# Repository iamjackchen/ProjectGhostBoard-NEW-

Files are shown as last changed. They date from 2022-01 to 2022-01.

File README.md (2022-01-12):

# ProjectGhostBoard

Hello thereeee

This is a site for me to document my current ongoing project a low profile wireless mechanical keyboard. Originally started this a few years ago back when I was in middle school (my macbook air had a semi-broken keyboard and I was just getting into the world of mechanical keyboards, AND there was a new set of low profile mechanical switches on the market) 

But who even knows anything about electronics engineering at that age? Took me a few years and attempts to slowly figure stuff out (you can see where I got to in my last attempt here, made when I was in G10: https://github.com/iamjackchen/ProjectGhostboard-OLD-)

<br/>

### About the Project

Enough with the history, moving onto the project itself. The original design goal was to build a low profile (i.e. portable) mechanical keyboard. The portable aspect also prompted me to pursue Bluetooth functionality ~~which might have possibly been the worst decision I have ever made in terms of trying to actually finish this project~~.
Here were my original design blueprints: 

<br/>

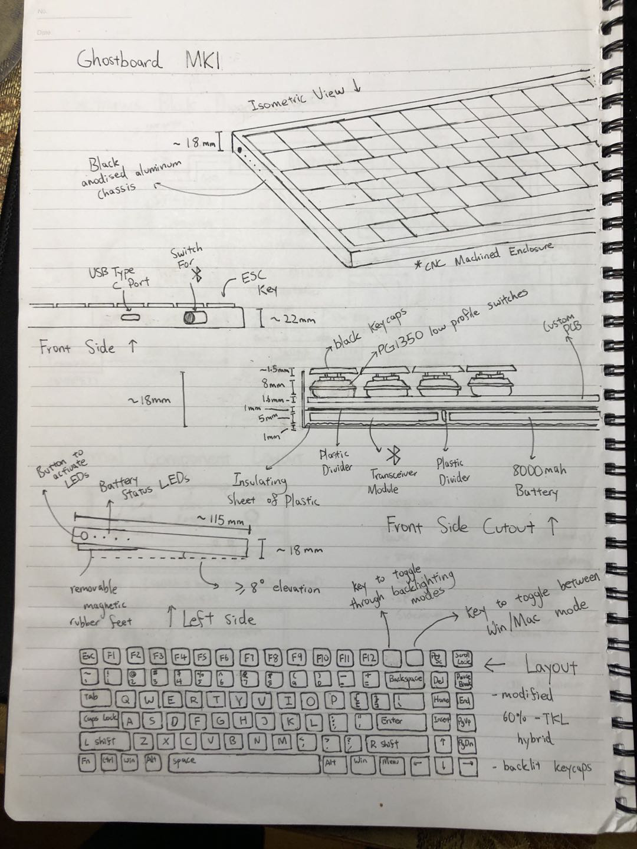
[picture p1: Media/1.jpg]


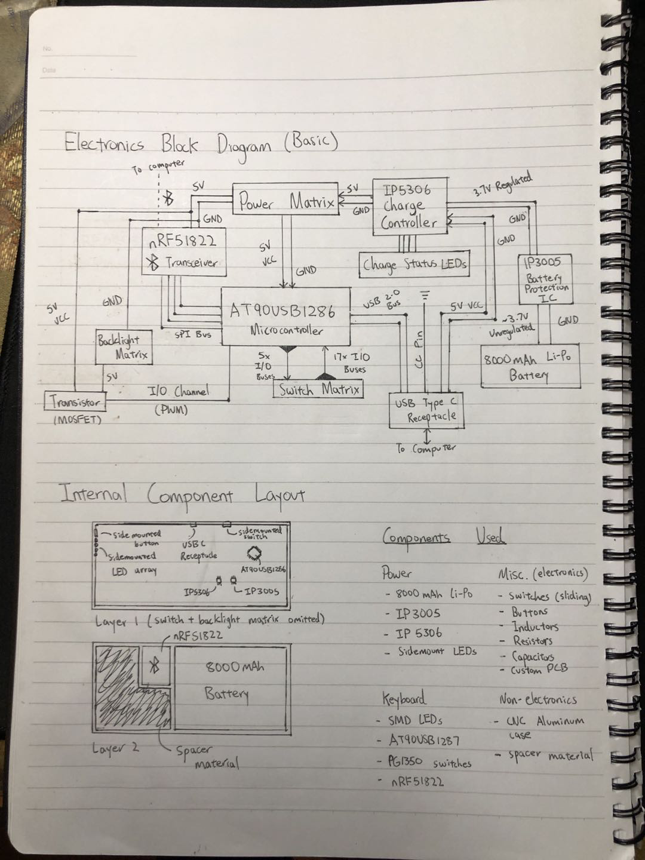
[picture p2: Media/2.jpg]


<br/>

The design has evolved a little (along with my knowledge of embedded systems and keyboard assembly 😂) but the general principle remains the same. A 75%-ish layout with PCB-mounted low profile switches (PG1350 - I'm using the brown/tactile variant) and white multi-level backlight. No disgusting rgb. Originally when the PG1350 line was released I tried to make this the first true low-profile wireless keyboard on the market but obviously that didn't happen lmao. The layout I eventually settled for is below:

<br/>

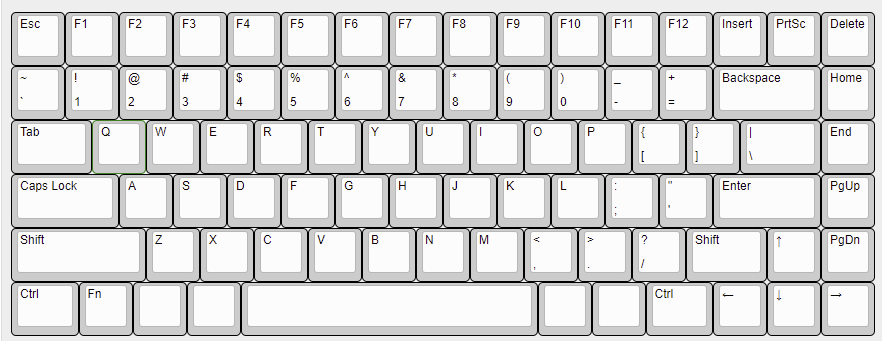
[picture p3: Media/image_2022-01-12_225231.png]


<br/>

The current PCB design (in the electronics folder) uses a USB-power gated MOSFET to regulate power delivery from the battery to the main circuit, an MCU-gated MOSFET to control charging (power flow to the battery) and a MCU-gated MOSFET to trigger Bluetooth. The intention of the MCU-gated control charging MOSFET is for the user to be able to disable charging when the keyboard is being plugged in over long periods of time for battery longevity. I'll probably use raw-hid to have some sort of computer-keyboard communication and write a desktop client that can tell the keyboard to disable charging. Maybe in the futre I can use raw-hid and a desktop client for other purposes (macros, backlight settings, and etc)

Some other design considerations and features with regards to electronics:
  - USB Type C
  - Battery charge indicator
  - HID over BLE

The software that makes all of this come together is [QMK](https://github.com/qmk/qmk_firmware). It's a keyboard firmware written in C and I am immensely grateful to its creators. And yes, for all new programmers here, do learn C or C++ before Python and *not* the other way around. You will thank me.

I havent gotten far enough to worry too much about the physical enclosure and keyboard assembly but I will have (hopefully) some CAD files, screenshots, and renders hanging out in this repo soon!! As of now I am aware that the PG1350 requires a thinner (1.2mm) plate and the stabilisers are mounted to the PCB (with plate cutouts needed). 

<br/>
If you've read this far, thank you so much for taking interest, and I hope to bear good news of progress soon. Below is a gallery of certain snippets from this awesome journey. 

----

# Gallery

### Current PCB Progress Renders (Coming soon)
Stay tuned.

<br/>

### Power Delivery Circuit Tester
Small PCB to test out my USB-C power delivery designs. Used an IC originally meant for power bank charging (IP5306 if anyone's interested) along with an FS8205A and a DW01 for battery surge protection. I had a lot of trouble soldering on header pins so I stripped two wires for it. Janky? Yes. But it works 😂

<br/>

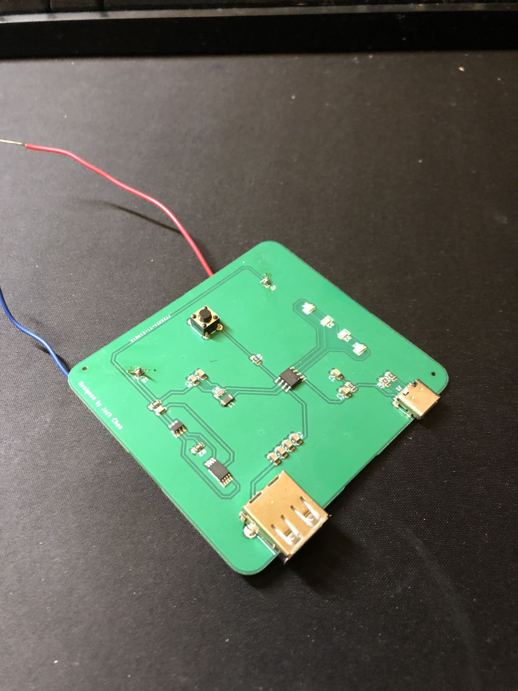
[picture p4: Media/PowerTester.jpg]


<br/>

Here's it in action with a 4000mAh lipo I had lying around from the last attempt at making this keyboard:

<br/>

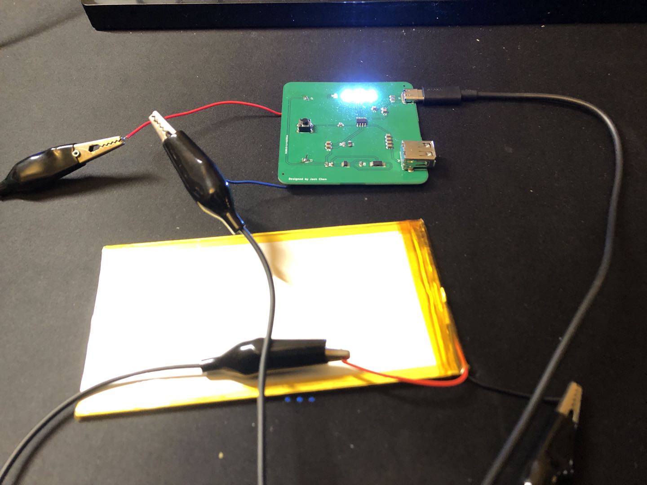
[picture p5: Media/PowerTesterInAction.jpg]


<br/>

### Proof of Concept
This is a demo of a proof of concept that my parents made me build before they would sponsor any further work of a custom  PCB. On the breadboard I have a Teensy2.0++ (ATUSB1286, the MCU I use in my custom PCB) wired to an Adafruit BLE module via SPI and a 4x4 tester matrix of generic buttons. I built this a while ago but lost the original video so I filmed it again a few days ago. Starring Antoni's new M1X MBP. 

<br/>

(https://youtu.be/-FnGQFiSdFY)

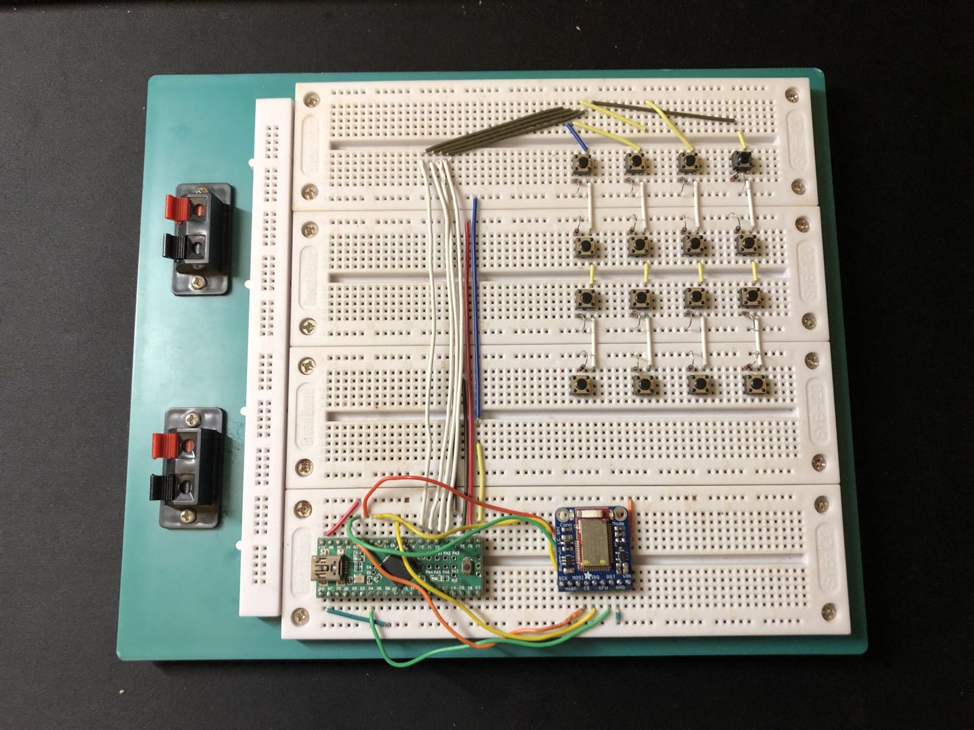
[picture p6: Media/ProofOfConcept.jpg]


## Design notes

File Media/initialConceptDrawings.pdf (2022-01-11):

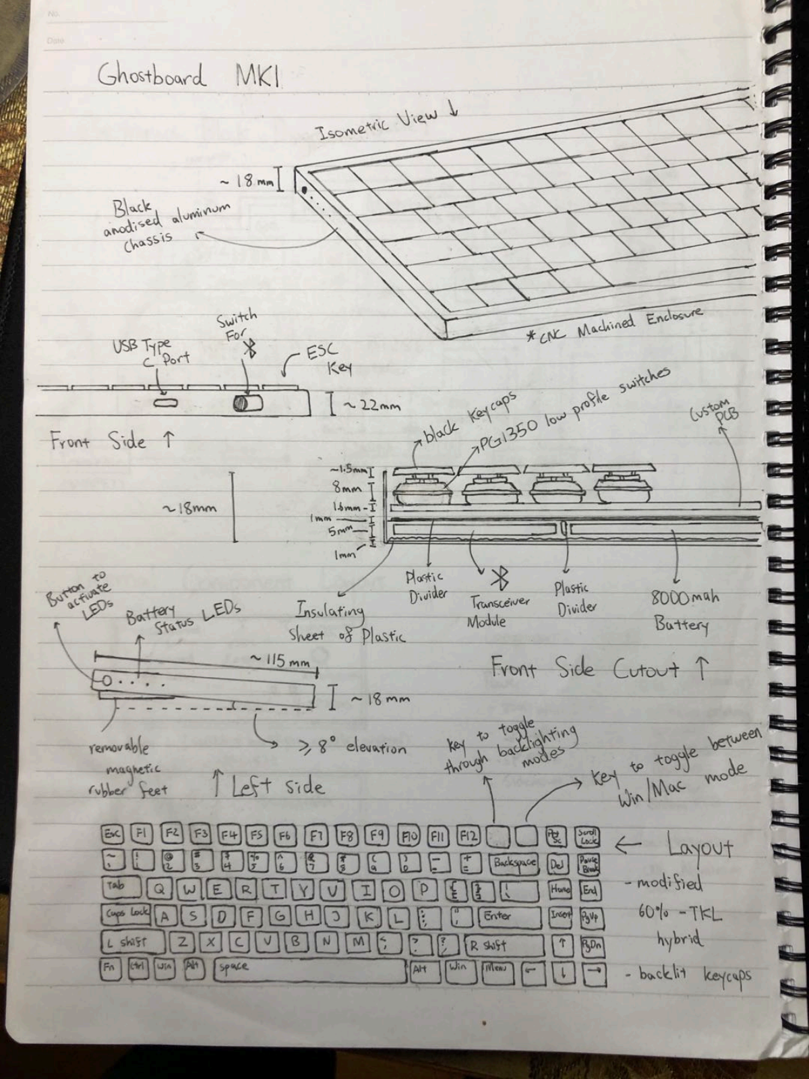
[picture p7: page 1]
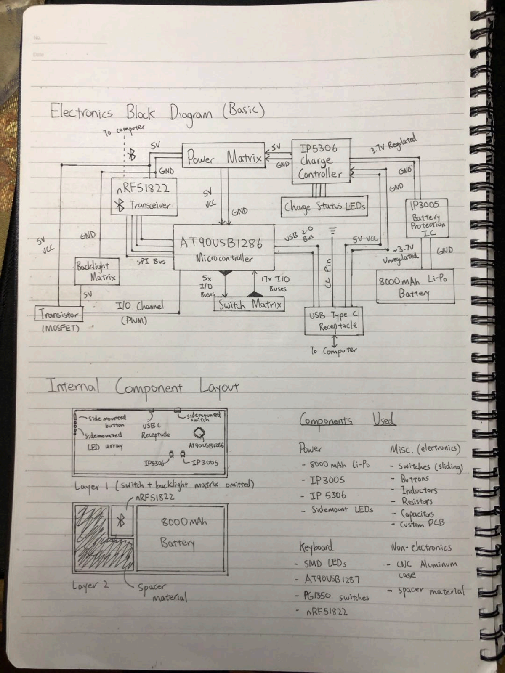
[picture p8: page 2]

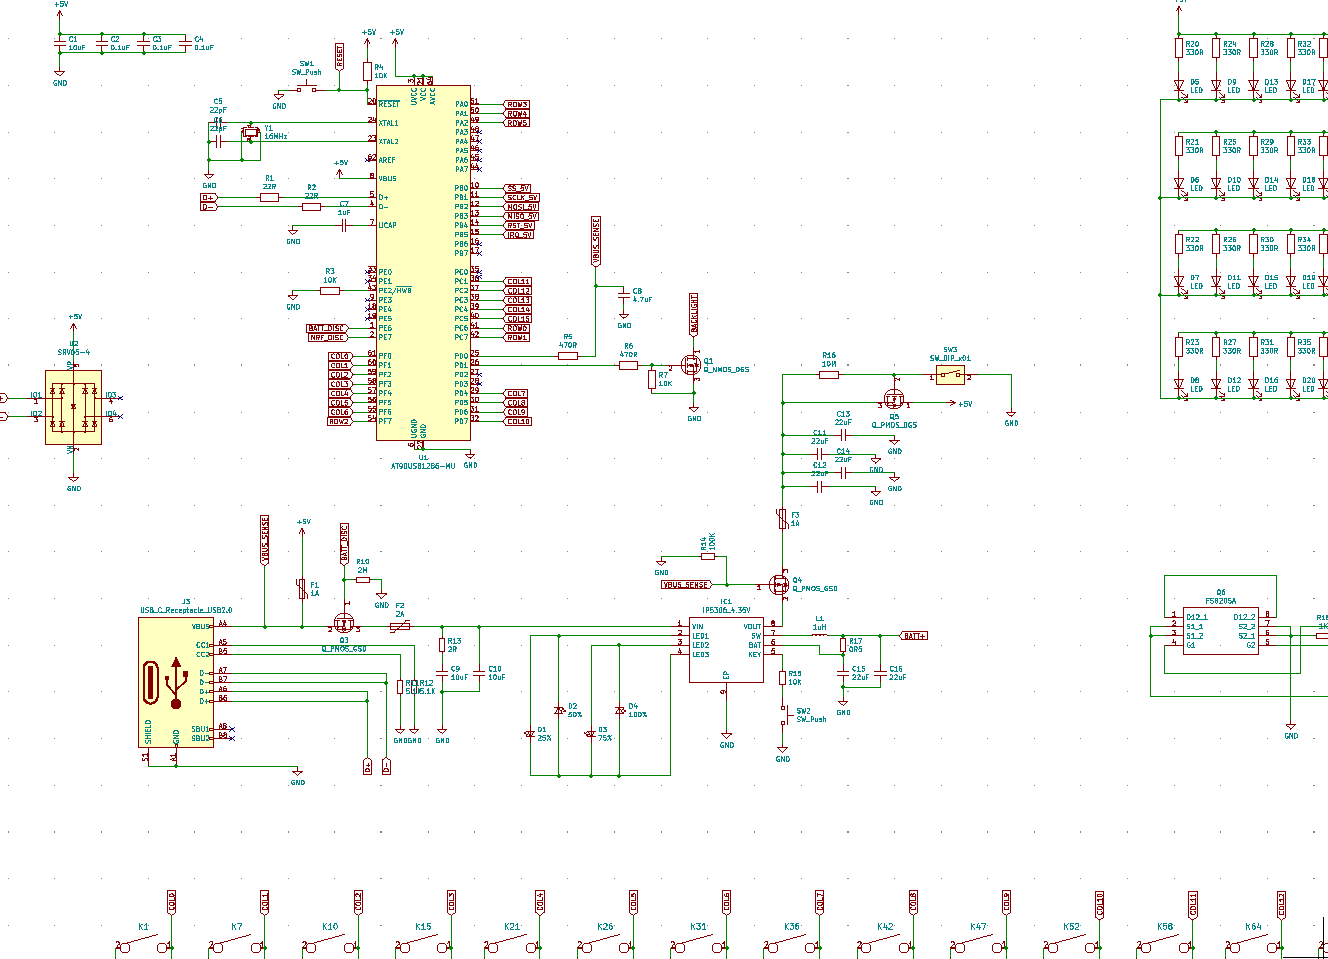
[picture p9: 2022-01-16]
Media/SchematicSS.png

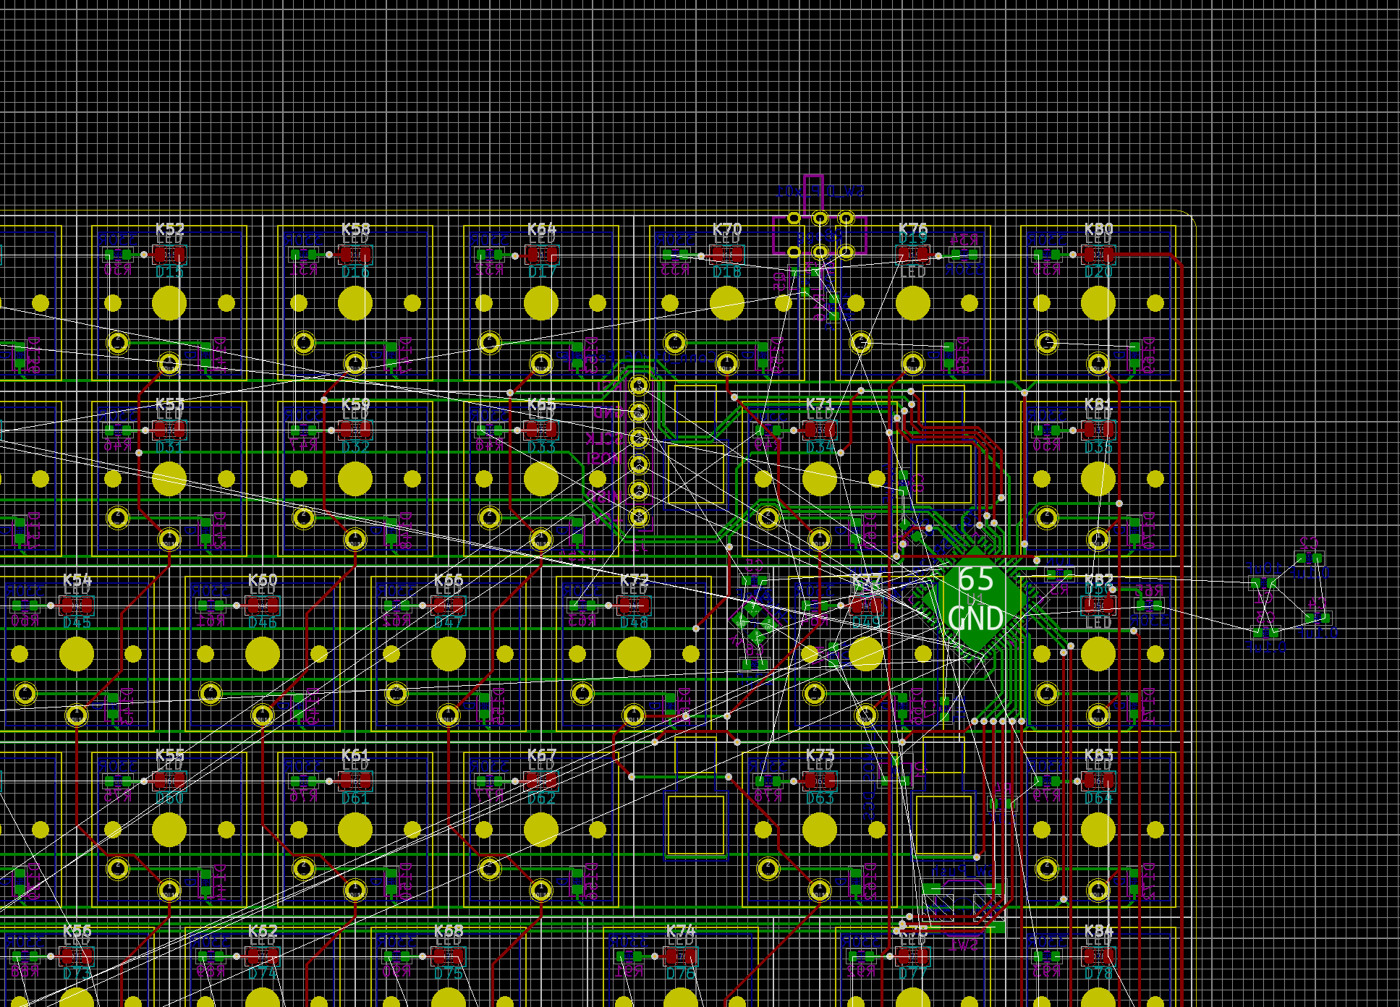
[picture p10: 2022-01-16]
Media/PCBSS.png

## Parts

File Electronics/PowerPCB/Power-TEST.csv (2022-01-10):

Comment | Designator | Footprint | LCSC
10uF | C1,C2 | Capacitor_SMD:C_0805_2012Metric_Pad1.18x1.45mm_HandSolder
0.1uF | C3 | Capacitor_SMD:C_0603_1608Metric_Pad1.08x0.95mm_HandSolder
22uF | C4,C5,C6,C7,C8,C9 | Capacitor_SMD:C_0805_2012Metric_Pad1.18x1.45mm_HandSolder
25% | D1 | LED_SMD:LED_0805_2012Metric_Pad1.15x1.40mm_HandSolder | C2290
50% | D2 | LED_SMD:LED_0805_2012Metric_Pad1.15x1.40mm_HandSolder | C2290
75% | D3 | LED_SMD:LED_0805_2012Metric_Pad1.15x1.40mm_HandSolder | C2290
100% | D4 | LED_SMD:LED_0805_2012Metric_Pad1.15x1.40mm_HandSolder | C2290
DW01 | IC1 | PCBFootprints:DW01 | C14213
IP5306_4.35V | IC2 | PCBFootprints:IP5306 | C384572
USB_C_Receptacle_USB2.0 | J1 | Connector_USB:USB_C_Receptacle_HRO_TYPE-C-31-M-12 | C136423
Cell+ | J2 | Connector_PinSocket_2.54mm:PinSocket_1x01_P2.54mm_Vertical
Cell- | J3 | Connector_PinSocket_2.54mm:PinSocket_1x01_P2.54mm_Vertical
USB_A | J4 | Connector_USB:USB_A_Stewart_SS-52100-001_Horizontal | C2346
1uH | L1 | Inductor_SMD:L_0805_2012Metric_Pad1.05x1.20mm_HandSolder
FS8205A | Q1 | PCBFootprints:FS8205A | C16052
2R | R1 | Resistor_SMD:R_0805_2012Metric_Pad1.20x1.40mm_HandSolder
1K | R2 | Resistor_SMD:R_0805_2012Metric_Pad1.20x1.40mm_HandSolder
100R | R3 | Resistor_SMD:R_0805_2012Metric_Pad1.20x1.40mm_HandSolder
10K | R4 | Resistor_SMD:R_0805_2012Metric_Pad1.20x1.40mm_HandSolder
0R5 | R5 | Resistor_SMD:R_0805_2012Metric_Pad1.20x1.40mm_HandSolder
5.1K | R6,R7 | Resistor_SMD:R_0805_2012Metric_Pad1.20x1.40mm_HandSolder
SW_Push | SW1 | Button_Switch_THT:SW_PUSH_6mm_H4.3mm

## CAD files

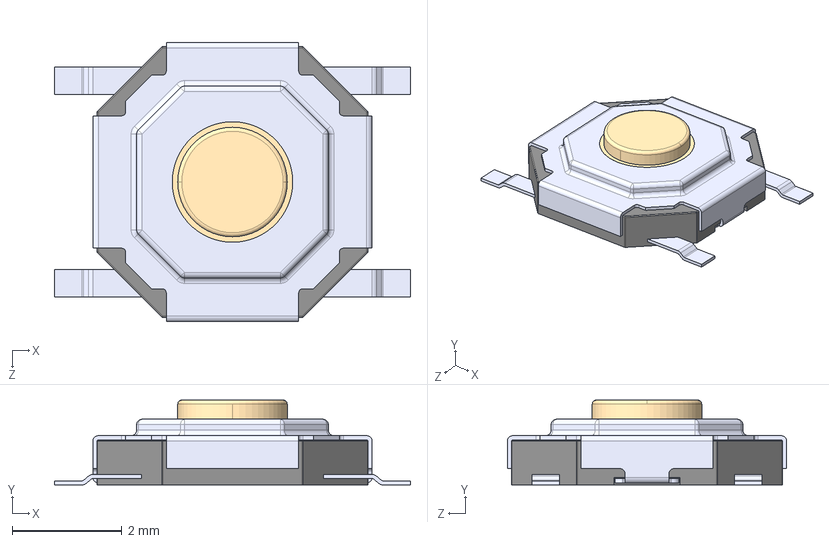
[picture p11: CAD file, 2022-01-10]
Electronics/PCBModels/TS-1187A-B-A-B.step
6.50 x 1.55 x 5.10 mm

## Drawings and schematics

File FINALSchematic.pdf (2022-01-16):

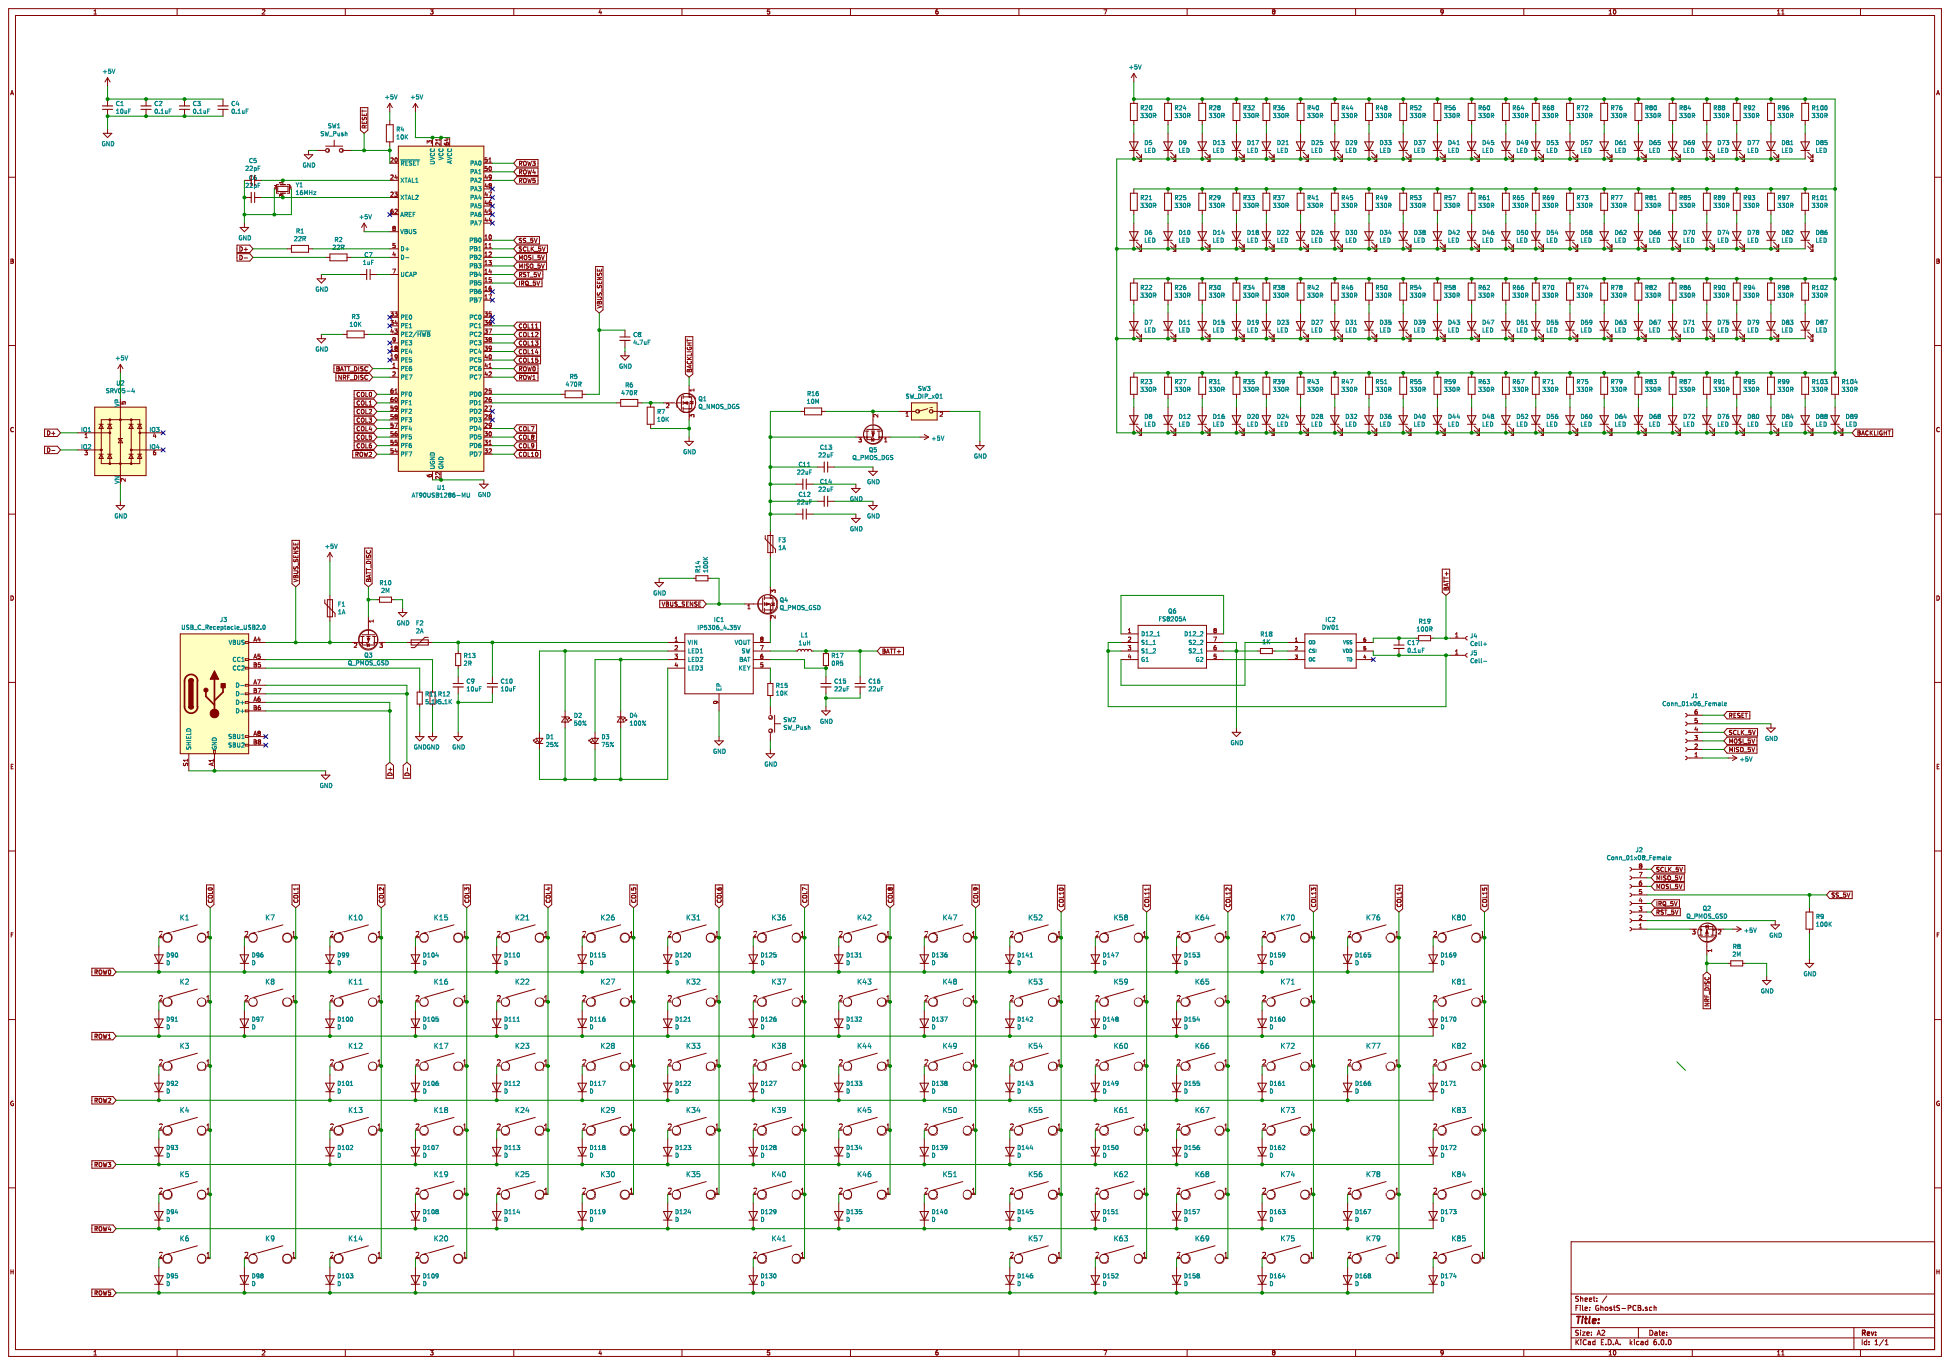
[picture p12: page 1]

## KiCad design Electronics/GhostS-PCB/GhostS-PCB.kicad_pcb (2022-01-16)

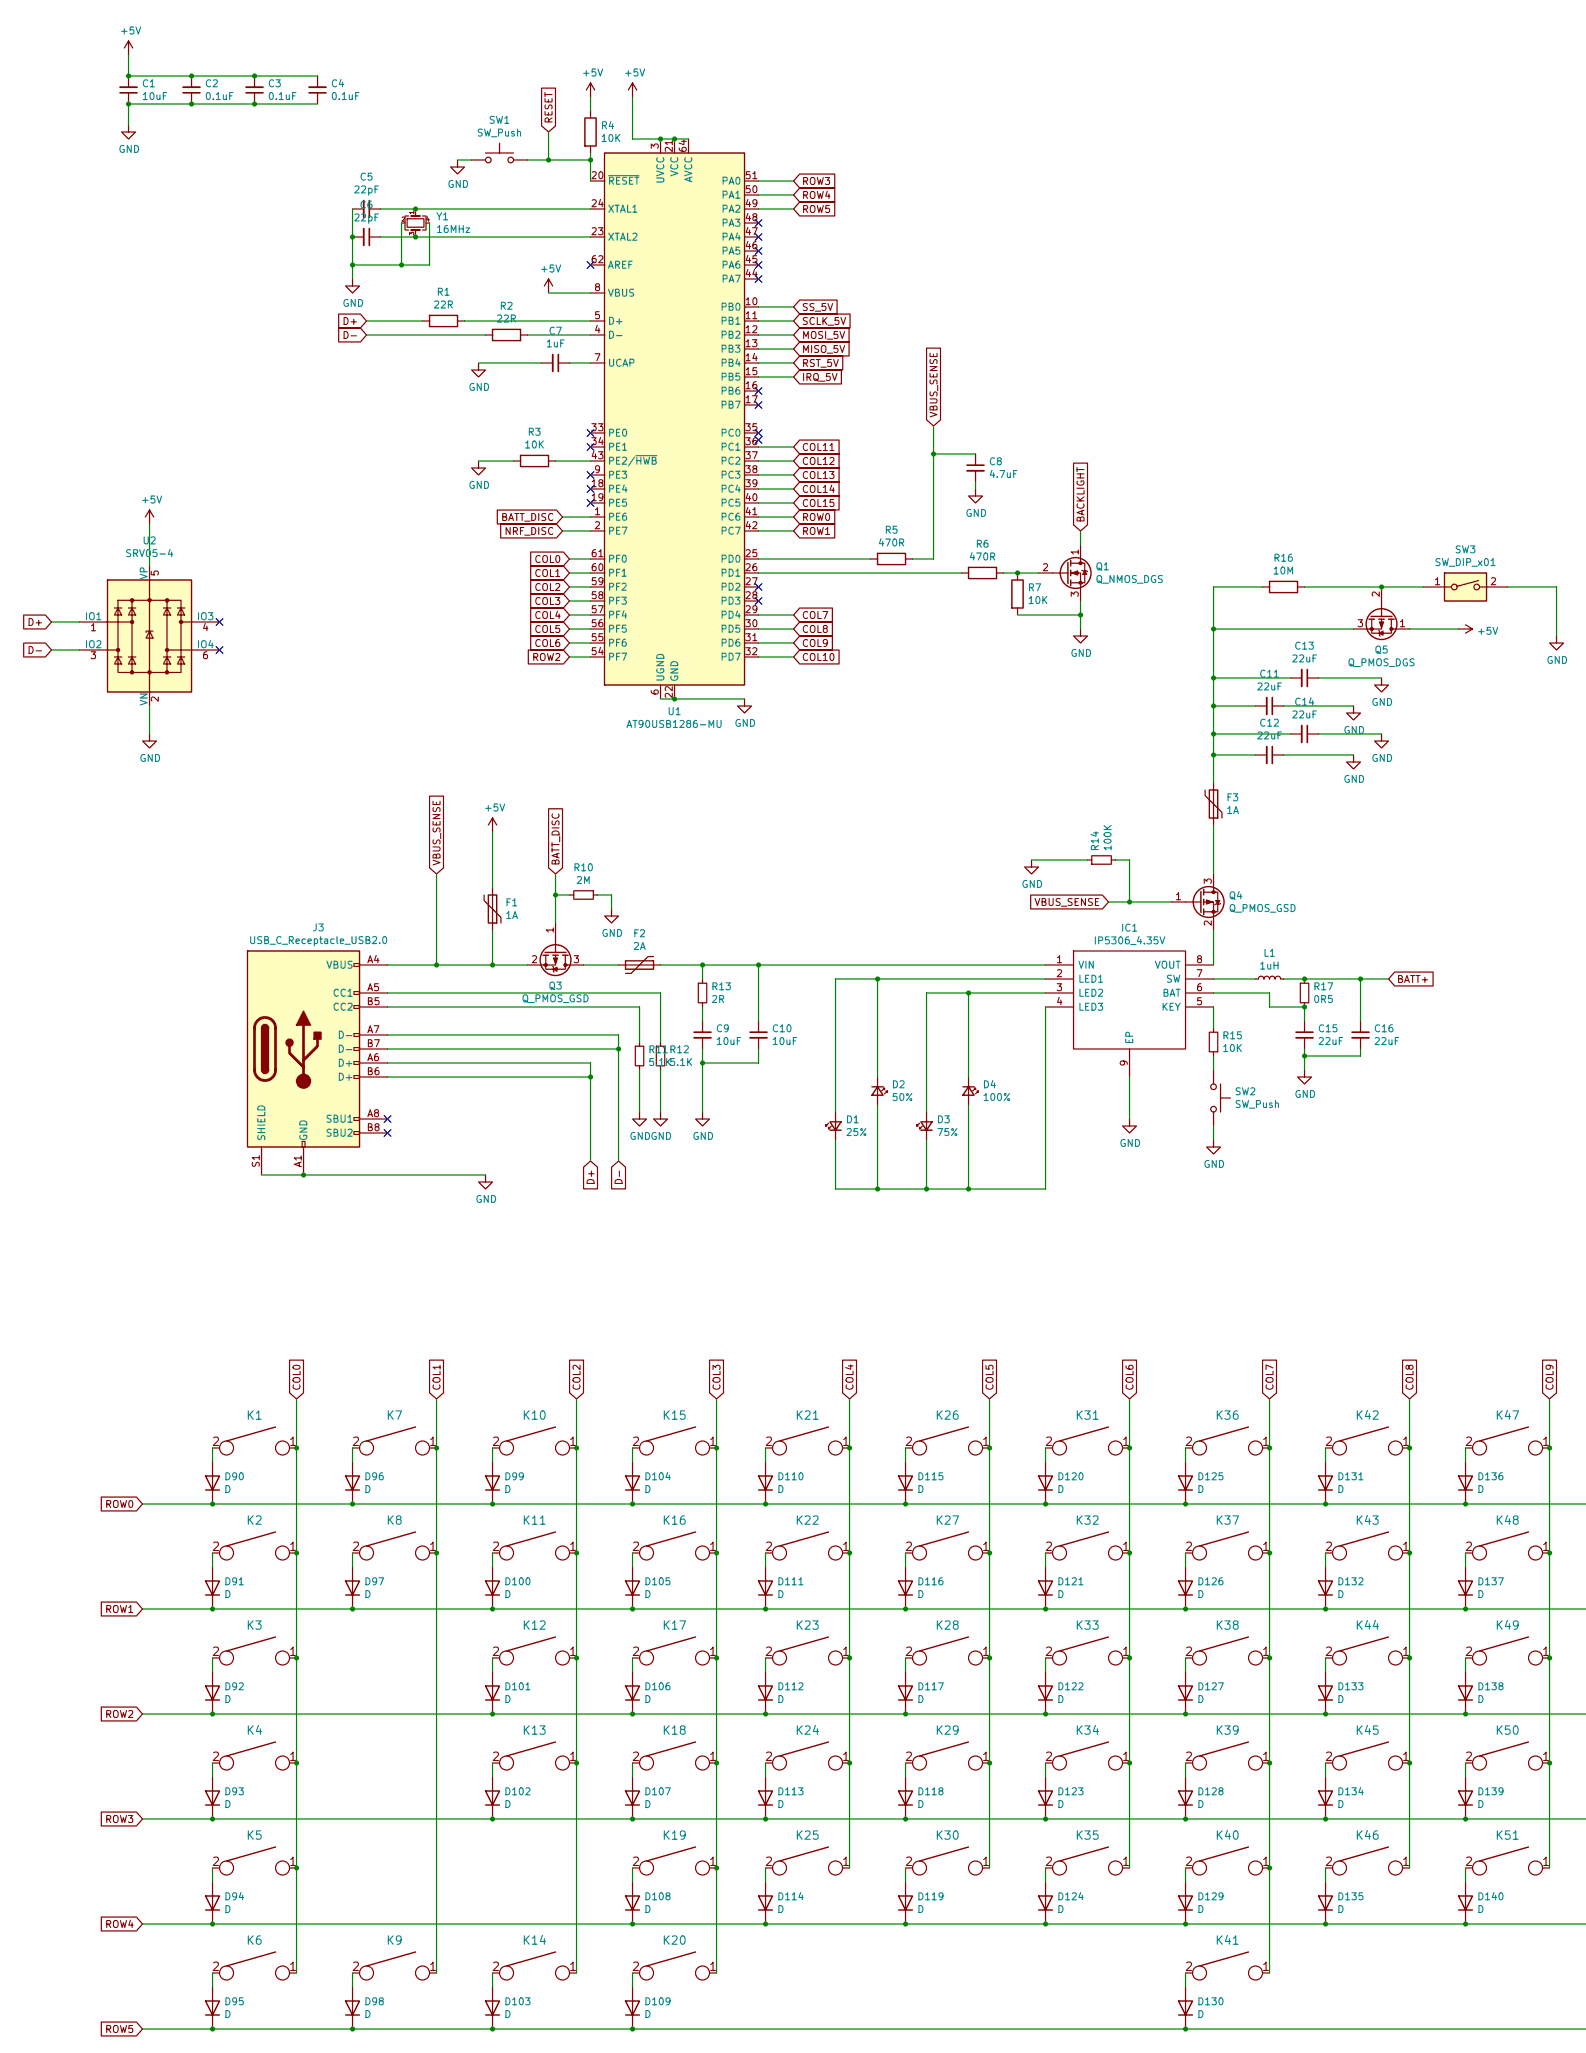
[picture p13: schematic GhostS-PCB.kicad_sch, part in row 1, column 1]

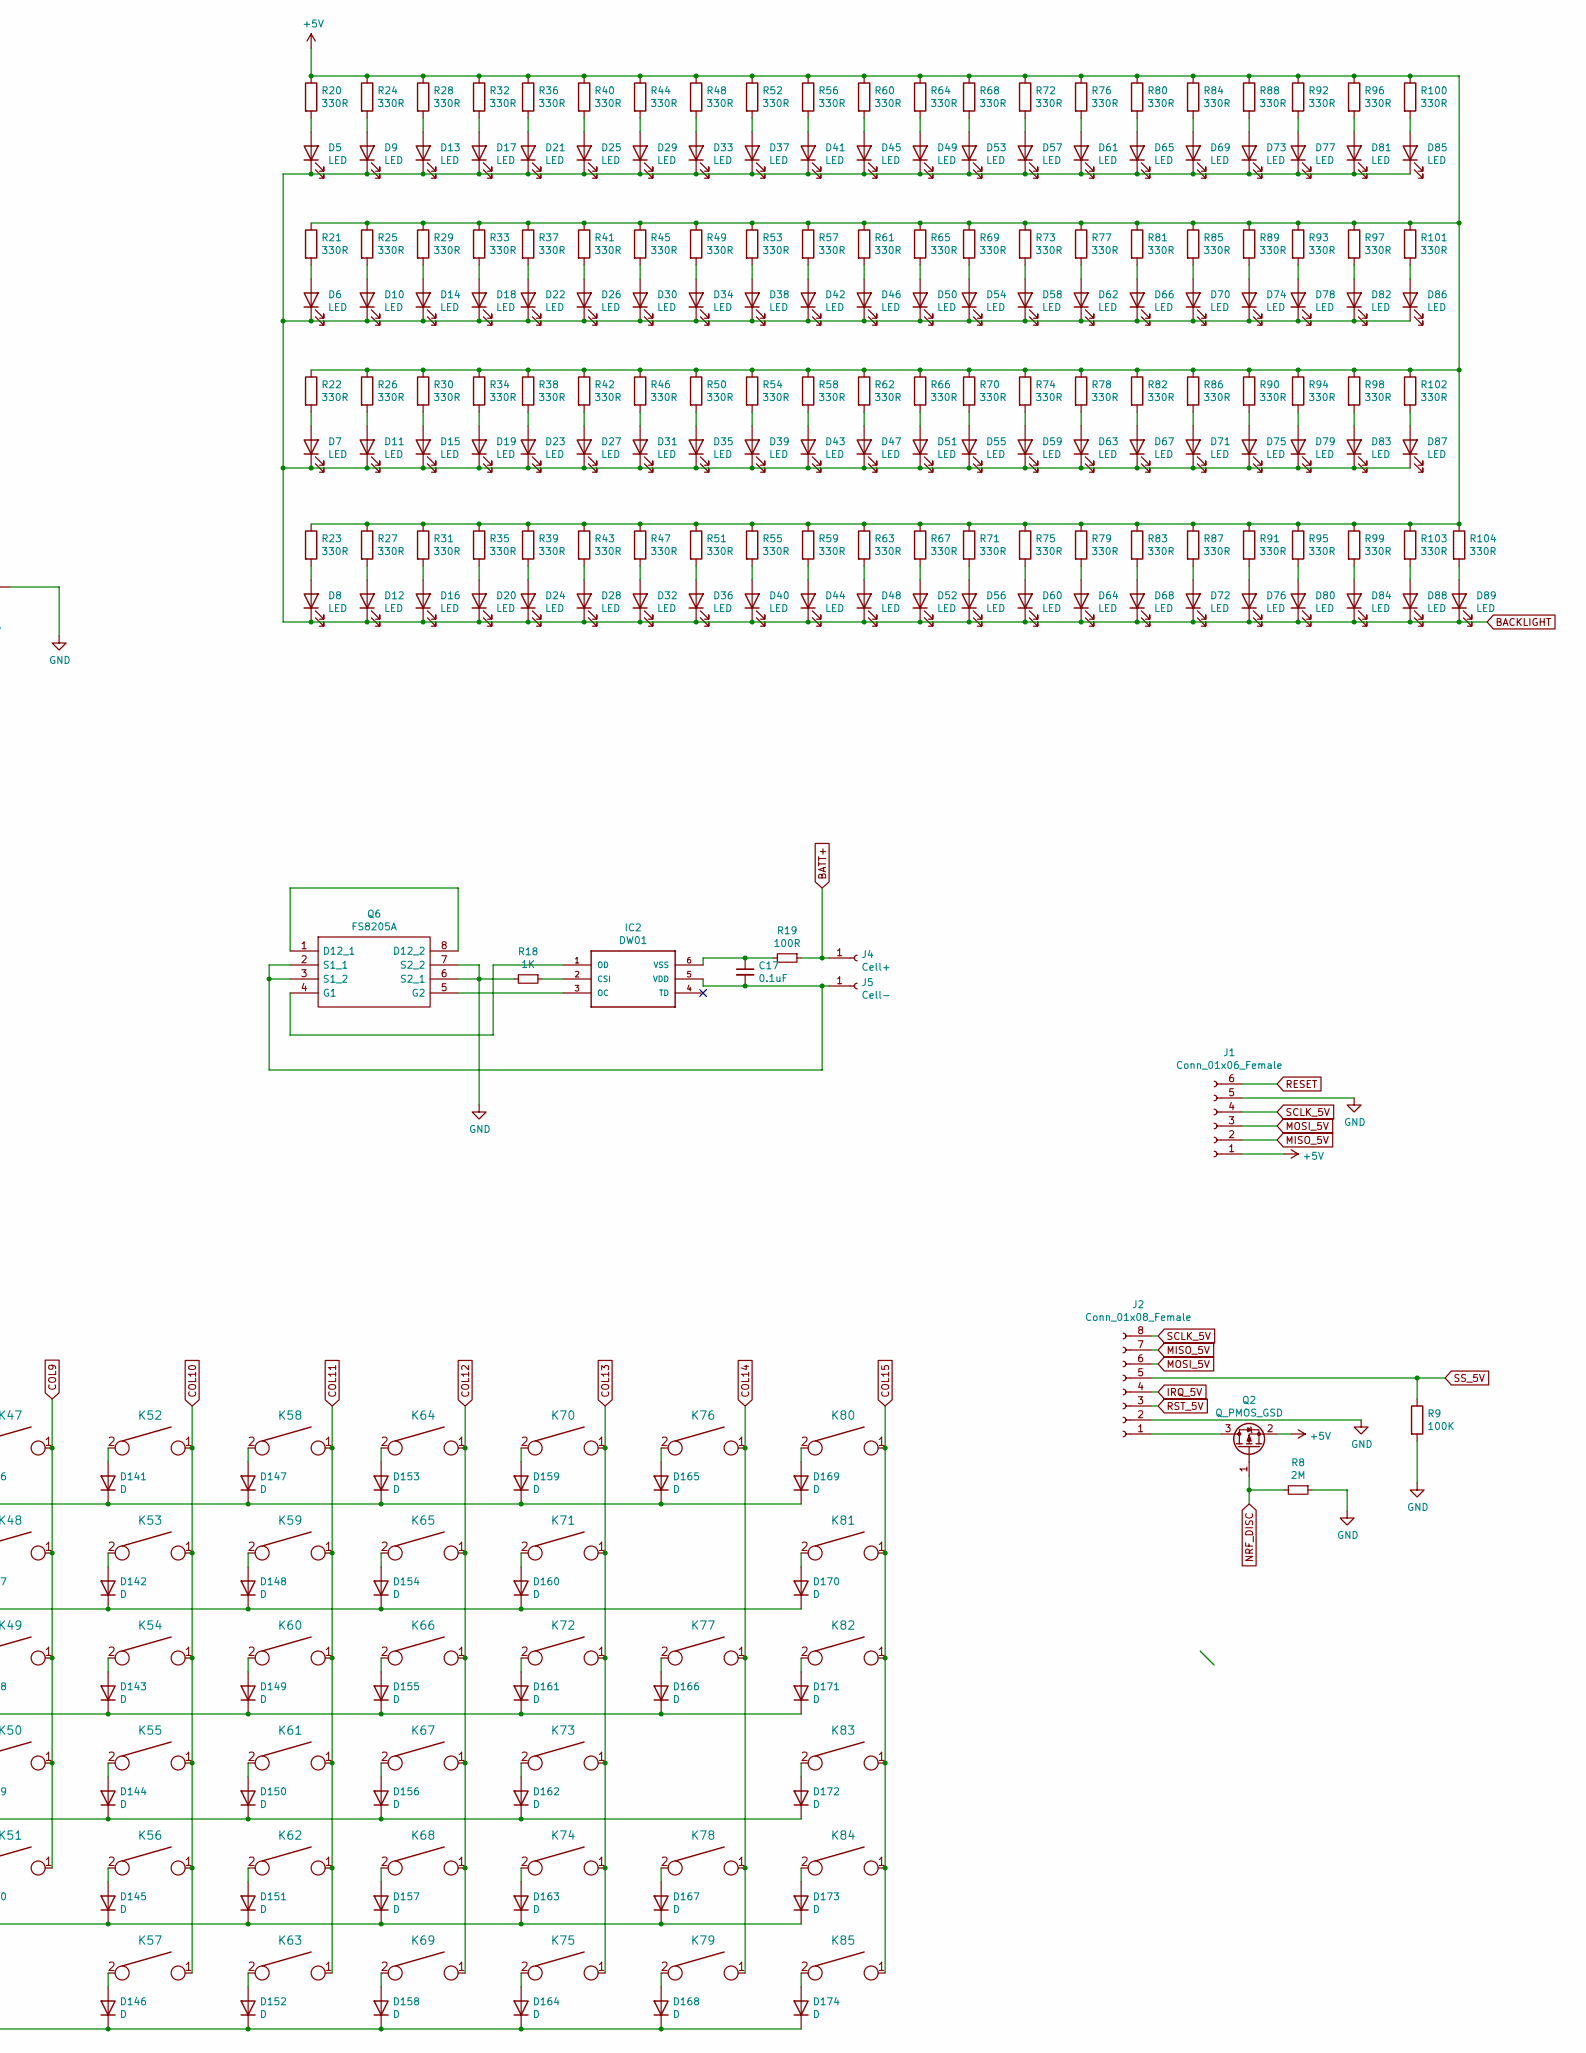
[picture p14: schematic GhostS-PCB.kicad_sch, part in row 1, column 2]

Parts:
C1, C9, C10: 10uF; C_0603_1608Metric
C2, C3, C4, C17: 0.1uF; C_0603_1608Metric
C5, C6: 22pF; C_0603_1608Metric
C7: 1uF; C_0603_1608Metric
C8: 4.7uF; C_0603_1608Metric
C11, C12, C13, C14, C15, C16: 22uF; C_0603_1608Metric
D1: 25%; LED_1206_3216Metric; LCSC C2290
D2: 50%; LED_1206_3216Metric; LCSC C2290
D3: 75%; LED_1206_3216Metric; LCSC C2290
D4: 100%; LED_1206_3216Metric; LCSC C2290
D5, D6, D7, D8, D9, D10, D11, D12, D13, D14, D15, D16, D17, D18, D19, D20, D21, D22, D23, D24, D25, D26, D27, D28, D29, D30, D31, D32, D33, D34, D35, D36, D37, D38, D39, D40, D41, D42, D43, D44, D45, D46, D47, D48, D49, D50, D51, D52, D53, D54, D55, D56, D57, D58, D59, D60, D61, D62, D63, D64, D65, D66, D67, D68, D69, D70, D71, D72, D73, D74, D75, D76, D77, D78, D79, D80, D81, D82, D83, D84, D85, D86, D87, D88, D89: LED; LED_0805_2012Metric
D90, D91, D92, D93, D94, D95, D96, D97, D98, D99, D100, D101, D102, D103, D104, D105, D106, D107, D108, D109, D110, D111, D112, D113, D114, D115, D116, D117, D118, D119, D120, D121, D122, D123, D124, D125, D126, D127, D128, D129, D130, D131, D132, D133, D134, D135, D136, D137, D138, D139, D140, D141, D142, D143, D144, D145, D146, D147, D148, D149, D150, D151, D152, D153, D154, D155, D156, D157, D158, D159, D160, D161, D162, D163, D164, D165, D166, D167, D168, D169, D170, D171, D172, D173, D174: D; D_0603_1608Metric
F1, F3: 1A; Fuse_1206_3216Metric
F2: 2A; Fuse_1206_3216Metric
IC1: IP5306_4.35V; IP5306; LCSC C384572
IC2: DW01; LCSC C14213
J1: Conn_01x06_Female; PinSocket_1x06_P2.54mm_Vertical
J2: Conn_01x08_Female; PinSocket_1x08_P2.54mm_Vertical
J3: USB_C_Receptacle_USB2.0; USB_C_Receptacle_HRO_TYPE-C-31-M-12; LCSC C136423
J4: Cell+; PinSocket_1x01_P2.54mm_Vertical
J5: Cell-; PinSocket_1x01_P2.54mm_Vertical
K1, K2, K3, K6, K7, K8, K9, K10, K11, K12, K13, K14, K15, K16, K17, K18, K19, K20, K21, K22, K23, K24, K25, K26, K27, K28, K29, K30, K31, K32, K33, K34, K35, K36, K37, K38, K39, K40, K42, K43, K44, K45, K46, K47, K48, K49, K50, K51, K52, K53, K54, K55, K56, K57, K58, K59, K60, K61, K62, K63, K64, K65, K66, K67, K68, K69, K70, K72, K74, K75, K76, K77, K78, K79, K80, K81, K82, K83, K84, K85: KEYSW; Kailh-PG1350-1u-NoLED
K4, K5, K71, K73: KEYSW; Kailh-PG1350-2u-NoLED
K41: KEYSW; Kailh-PG1350-5.5u-NoLED
L1: 1uH; L_0805_2012Metric_Pad1.05x1.20mm_HandSolder
Q1: Q_NMOS_DGS; SOT-23
Q2, Q3, Q4: Q_PMOS_GSD; SOT-23
Q5: Q_PMOS_DGS; SOT-23
Q6: FS8205A; LCSC C16052
R1, R2: 22R; R_0603_1608Metric
R3, R4, R7, R15: 10K; R_0603_1608Metric
R5, R6: 470R; R_0603_1608Metric
R8, R10: 2M; R_0603_1608Metric
R9, R14: 100K; R_0603_1608Metric
R11, R12: 5.1K; R_0603_1608Metric
R13: 2R; R_0603_1608Metric
R16: 10M; R_0603_1608Metric
R17: 0R5; R_0603_1608Metric
R18: 1K; R_0603_1608Metric
R19: 100R; R_0603_1608Metric
R20, R21, R22, R23, R24, R25, R26, R27, R28, R29, R30, R31, R32, R33, R34, R35, R36, R37, R38, R39, R40, R41, R42, R43, R44, R45, R46, R47, R48, R49, R50, R51, R52, R53, R54, R55, R56, R57, R58, R59, R60, R61, R62, R63, R64, R65, R66, R67, R68, R69, R70, R71, R72, R73, R74, R75, R76, R77, R78, R79, R80, R81, R82, R83, R84, R85, R86, R87, R88, R89, R90, R91, R92, R93, R94, R95, R96, R97, R98, R99, R100, R101, R102, R103, R104: 330R; R_0603_1608Metric
SW1: SW_Push; SW_SPST_SKQG_WithStem
SW2: SW_Push; TS-1186D
SW3: SW_DIP_x01; SW-TH_SK-3245D-02-L4.00
U1: AT90USB1286-MU; QFN-64-1EP_9x9mm_P0.5mm_EP7.5x7.5mm
U2: SRV05-4; SOT-23-6
Y1: 16MHz; Crystal_SMD_3225-4pin_3.2x2.5mm

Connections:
+5V: C1.2, C2.2, C3.2, C4.2, F1.2, J1.1, Q2.2 (S), Q5.1 (D), R4.1, R20.1, R21.1, R22.1, R23.1, R24.1, R25.1, R26.1, R27.1, R28.1, R29.1, R30.1, R31.1, R32.1, R33.1, R34.1, R35.1, R36.1, R37.1, R38.1, R39.1, R40.1, R41.1, R42.1, R43.1, R44.1, R45.1, R46.1, R47.1, R48.1, R49.1, R50.1, R51.1, R52.1, R53.1, R54.1, R55.1, R56.1, R57.1, R58.1, R59.1, R60.1, R61.1, R62.1, R63.1, R64.1, R65.1, R66.1, R67.1, R68.1, R69.1, R70.1, R71.1, R72.1, R73.1, R74.1, R75.1, R76.1, R77.1, R78.1, R79.1, R80.1, R81.1, R82.1, R83.1, R84.1, R85.1, R86.1, R87.1, R88.1, R89.1, R90.1, R91.1, R92.1, R93.1, R94.1, R95.1, R96.1, R97.1, R98.1, R99.1, R100.1, R101.1, R102.1, R103.1, R104.1, U1.3 (UVCC), U1.8 (VBUS), U1.21 (VCC), U1.52 (VCC), U1.64 (AVCC), U2.5 (VP); also elsewhere on the board
BACKLIGHT: D5.1 (K), D6.1 (K), D7.1 (K), D8.1 (K), D9.1 (K), D10.1 (K), D11.1 (K), D12.1 (K), D13.1 (K), D14.1 (K), D15.1 (K), D16.1 (K), D17.1 (K), D18.1 (K), D19.1 (K), D20.1 (K), D21.1 (K), D22.1 (K), D23.1 (K), D24.1 (K), D25.1 (K), D26.1 (K), D27.1 (K), D28.1 (K), D29.1 (K), D30.1 (K), D31.1 (K), D32.1 (K), D33.1 (K), D34.1 (K), D35.1 (K), D36.1 (K), D37.1 (K), D38.1 (K), D39.1 (K), D40.1 (K), D41.1 (K), D42.1 (K), D43.1 (K), D44.1 (K), D45.1 (K), D46.1 (K), D47.1 (K), D48.1 (K), D49.1 (K), D50.1 (K), D51.1 (K), D52.1 (K), D53.1 (K), D54.1 (K), D55.1 (K), D56.1 (K), D57.1 (K), D58.1 (K), D59.1 (K), D60.1 (K), D61.1 (K), D62.1 (K), D63.1 (K), D64.1 (K), D65.1 (K), D66.1 (K), D67.1 (K), D68.1 (K), D69.1 (K), D70.1 (K), D71.1 (K), D72.1 (K), D73.1 (K), D74.1 (K), D75.1 (K), D76.1 (K), D77.1 (K), D78.1 (K), D79.1 (K), D80.1 (K), D81.1 (K), D82.1 (K), D83.1 (K), D84.1 (K), D85.1 (K), D86.1 (K), D87.1 (K), D88.1 (K), D89.1 (K), Q1.1 (D)
BATT+: C16.1, J4.1, L1.2, R17.1, R19.1
BATT_DISC: Q3.1 (G), R10.2, U1.1 (PE6)
COL0: K1.1, K2.1, K3.1, K4.1, K5.1, K6.1, U1.61 (PF0)
COL1: K7.1, K8.1, K9.1, U1.60 (PF1)
COL2: K10.1, K11.1, K12.1, K13.1, K14.1, U1.59 (PF2)
COL3: K15.1, K16.1, K17.1, K18.1, K19.1, K20.1, U1.58 (PF3)
COL4: K21.1, K22.1, K23.1, K24.1, K25.1, U1.57 (PF4)
COL5: K26.1, K27.1, K28.1, K29.1, K30.1, U1.56 (PF5)
COL6: K31.1, K32.1, K33.1, K34.1, K35.1, U1.55 (PF6)
COL7: K36.1, K37.1, K38.1, K39.1, K40.1, K41.1, U1.29 (PD4)
COL8: K42.1, K43.1, K44.1, K45.1, K46.1, U1.30 (PD5)
COL9: K47.1, K48.1, K49.1, K50.1, K51.1, U1.31 (PD6)
COL10: K52.1, K53.1, K54.1, K55.1, K56.1, K57.1, U1.32 (PD7)
COL11: K58.1, K59.1, K60.1, K61.1, K62.1, K63.1, U1.36 (PC1)
COL12: K64.1, K65.1, K66.1, K67.1, K68.1, K69.1, U1.37 (PC2)
COL13: K70.1, K71.1, K72.1, K73.1, K74.1, K75.1, U1.38 (PC3)
COL14: K76.1, K77.1, K78.1, K79.1, U1.39 (PC4)
COL15: K80.1, K81.1, K82.1, K83.1, K84.1, K85.1, U1.40 (PC5)
D+: J3.A6 (D+), J3.B6 (D+), R1.2, U2.1 (IO1)
D-: J3.A7 (D-), J3.B7 (D-), R2.1, U2.3 (IO2)
GND: C1.1, C2.1, C3.1, C4.1, C5.2, C6.2, C7.2, C8.2, C9.2, C10.2, C11.1, C12.1, C13.1, C14.1, C15.2, C16.2, IC1.9 (EP), J1.5, J2.2, J3.A1 (GND), J3.A12 (GND), J3.B1 (GND), J3.B12 (GND), J3.S1 (SHIELD), Q1.3 (S), Q6.6 (S2_1), Q6.7 (S2_2), R3.2, R7.2, R8.1, R9.2, R10.1, R11.2, R12.2, R14.1, R18.2, SW1.1, SW2.2, SW3.2, U1.6 (UGND), U1.22 (GND), U1.53 (GND), U1.63 (GND), U1.65 (GND), U2.2 (VN), Y1.2, Y1.4
IRQ_5V: J2.4, U1.15 (PB5)
MISO_5V: J1.2, J2.7, U1.13 (PB3)
MOSI_5V: J1.3, J2.6, U1.12 (PB2)
NRF_DISC: Q2.1 (G), R8.2, U1.2 (PE7)
unnamed: C5.1, U1.24 (XTAL1), Y1.1
unnamed: C6.1, U1.23 (XTAL2), Y1.3
unnamed: C7.1, U1.7 (UCAP)
unnamed: C9.1, R13.2
unnamed: C10.1, F2.1, IC1.1 (VIN), R13.1
unnamed: C11.2, C12.2, C13.2, C14.2, F3.2, Q5.3 (S), R16.2
unnamed: C15.1, IC1.6 (BAT), R17.2
unnamed: C17.1, IC2.6 (VSS), R19.2
unnamed: C17.2, IC2.5 (VDD), J5.1, Q6.2 (S1_1), Q6.3 (S1_2)
unnamed: D1.1 (K), D2.2 (A), D3.1 (K), D4.2 (A), IC1.4 (LED3)
unnamed: D1.2 (A), D2.1 (K), IC1.2 (LED1)
unnamed: D3.2 (A), D4.1 (K), IC1.3 (LED2)
unnamed: D5.2 (A), R20.2
unnamed: D6.2 (A), R21.2
unnamed: D7.2 (A), R22.2
unnamed: D8.2 (A), R23.2
unnamed: D9.2 (A), R24.2
unnamed: D10.2 (A), R25.2
unnamed: D11.2 (A), R26.2
unnamed: D12.2 (A), R27.2
unnamed: D13.2 (A), R28.2
unnamed: D14.2 (A), R29.2
unnamed: D15.2 (A), R30.2
unnamed: D16.2 (A), R31.2
unnamed: D17.2 (A), R32.2
unnamed: D18.2 (A), R33.2
unnamed: D19.2 (A), R34.2
unnamed: D20.2 (A), R35.2
unnamed: D21.2 (A), R36.2
unnamed: D22.2 (A), R37.2
unnamed: D23.2 (A), R38.2
unnamed: D24.2 (A), R39.2
unnamed: D25.2 (A), R40.2
unnamed: D26.2 (A), R41.2
unnamed: D27.2 (A), R42.2
unnamed: D28.2 (A), R43.2
unnamed: D29.2 (A), R44.2
unnamed: D30.2 (A), R45.2
unnamed: D31.2 (A), R46.2
unnamed: D32.2 (A), R47.2
unnamed: D33.2 (A), R48.2
unnamed: D34.2 (A), R49.2
unnamed: D35.2 (A), R50.2
unnamed: D36.2 (A), R51.2
unnamed: D37.2 (A), R52.2
unnamed: D38.2 (A), R53.2
unnamed: D39.2 (A), R54.2
unnamed: D40.2 (A), R55.2
unnamed: D41.2 (A), R56.2
unnamed: D42.2 (A), R57.2
unnamed: D43.2 (A), R58.2
unnamed: D44.2 (A), R59.2
unnamed: D45.2 (A), R60.2
unnamed: D46.2 (A), R61.2
unnamed: D47.2 (A), R62.2
unnamed: D48.2 (A), R63.2
unnamed: D49.2 (A), R64.2
unnamed: D50.2 (A), R65.2
unnamed: D51.2 (A), R66.2
unnamed: D52.2 (A), R67.2
unnamed: D53.2 (A), R68.2
unnamed: D54.2 (A), R69.2
unnamed: D55.2 (A), R70.2
unnamed: D56.2 (A), R71.2
unnamed: D57.2 (A), R72.2
unnamed: D58.2 (A), R73.2
unnamed: D59.2 (A), R74.2
unnamed: D60.2 (A), R75.2
unnamed: D61.2 (A), R76.2
unnamed: D62.2 (A), R77.2
unnamed: D63.2 (A), R78.2
unnamed: D64.2 (A), R79.2
unnamed: D65.2 (A), R80.2
unnamed: D66.2 (A), R81.2
unnamed: D67.2 (A), R82.2
unnamed: D68.2 (A), R83.2
unnamed: D69.2 (A), R84.2
unnamed: D70.2 (A), R85.2
unnamed: D71.2 (A), R86.2
unnamed: D72.2 (A), R87.2
unnamed: D73.2 (A), R88.2
unnamed: D74.2 (A), R89.2
unnamed: D75.2 (A), R90.2
unnamed: D76.2 (A), R91.2
unnamed: D77.2 (A), R92.2
unnamed: D78.2 (A), R93.2
unnamed: D79.2 (A), R94.2
unnamed: D80.2 (A), R95.2
unnamed: D81.2 (A), R96.2
unnamed: D82.2 (A), R97.2
unnamed: D83.2 (A), R98.2
unnamed: D84.2 (A), R99.2
unnamed: D85.2 (A), R100.2
unnamed: D86.2 (A), R101.2
unnamed: D87.2 (A), R102.2
unnamed: D88.2 (A), R103.2
unnamed: D89.2 (A), R104.2
unnamed: D90.2 (A), K1.2
unnamed: D91.2 (A), K2.2
unnamed: D92.2 (A), K3.2
unnamed: D93.2 (A), K4.2
unnamed: D94.2 (A), K5.2
unnamed: D95.2 (A), K6.2
unnamed: D96.2 (A), K7.2
unnamed: D97.2 (A), K8.2
unnamed: D98.2 (A), K9.2
unnamed: D99.2 (A), K10.2
unnamed: D100.2 (A), K11.2
unnamed: D101.2 (A), K12.2
unnamed: D102.2 (A), K13.2
unnamed: D103.2 (A), K14.2
unnamed: D104.2 (A), K15.2
unnamed: D105.2 (A), K16.2
unnamed: D106.2 (A), K17.2
unnamed: D107.2 (A), K18.2
unnamed: D108.2 (A), K19.2
unnamed: D109.2 (A), K20.2
unnamed: D110.2 (A), K21.2
unnamed: D111.2 (A), K22.2
unnamed: D112.2 (A), K23.2
unnamed: D113.2 (A), K24.2
unnamed: D114.2 (A), K25.2
unnamed: D115.2 (A), K26.2
unnamed: D116.2 (A), K27.2
unnamed: D117.2 (A), K28.2
unnamed: D118.2 (A), K29.2
unnamed: D119.2 (A), K30.2
unnamed: D120.2 (A), K31.2
unnamed: D121.2 (A), K32.2
unnamed: D122.2 (A), K33.2
unnamed: D123.2 (A), K34.2
unnamed: D124.2 (A), K35.2
unnamed: D125.2 (A), K36.2
unnamed: D126.2 (A), K37.2
unnamed: D127.2 (A), K38.2
unnamed: D128.2 (A), K39.2
unnamed: D129.2 (A), K40.2
unnamed: D130.2 (A), K41.2
unnamed: D131.2 (A), K42.2
unnamed: D132.2 (A), K43.2
unnamed: D133.2 (A), K44.2
unnamed: D134.2 (A), K45.2
unnamed: D135.2 (A), K46.2
unnamed: D136.2 (A), K47.2
unnamed: D137.2 (A), K48.2
unnamed: D138.2 (A), K49.2
unnamed: D139.2 (A), K50.2
unnamed: D140.2 (A), K51.2
unnamed: D141.2 (A), K52.2
unnamed: D142.2 (A), K53.2
unnamed: D143.2 (A), K54.2
unnamed: D144.2 (A), K55.2
unnamed: D145.2 (A), K56.2
unnamed: D146.2 (A), K57.2
unnamed: D147.2 (A), K58.2
unnamed: D148.2 (A), K59.2
unnamed: D149.2 (A), K60.2
unnamed: D150.2 (A), K61.2
unnamed: D151.2 (A), K62.2
unnamed: D152.2 (A), K63.2
unnamed: D153.2 (A), K64.2
unnamed: D154.2 (A), K65.2
unnamed: D155.2 (A), K66.2
unnamed: D156.2 (A), K67.2
unnamed: D157.2 (A), K68.2
unnamed: D158.2 (A), K69.2
unnamed: D159.2 (A), K70.2
unnamed: D160.2 (A), K71.2
unnamed: D161.2 (A), K72.2
unnamed: D162.2 (A), K73.2
unnamed: D163.2 (A), K74.2
unnamed: D164.2 (A), K75.2
unnamed: D165.2 (A), K76.2
unnamed: D166.2 (A), K77.2
unnamed: D167.2 (A), K78.2
unnamed: D168.2 (A), K79.2
unnamed: D169.2 (A), K80.2
unnamed: D170.2 (A), K81.2
unnamed: D171.2 (A), K82.2
unnamed: D172.2 (A), K83.2
unnamed: D173.2 (A), K84.2
unnamed: D174.2 (A), K85.2
unnamed: F2.2, Q3.3 (D)
unnamed: F3.1, Q4.3 (D)
unnamed: IC1.5 (KEY), R15.2
unnamed: IC1.7 (SW), L1.1
unnamed: IC1.8 (VOUT), Q4.2 (S)
unnamed: IC2.1 (OD), Q6.4 (G1)
unnamed: IC2.2 (CSI), R18.1
unnamed: IC2.3 (OC), Q6.5 (G2)
unnamed: J2.1, Q2.3 (D)
unnamed: J3.A5 (CC1), R12.1
unnamed: J3.B5 (CC2), R11.1
unnamed: Q1.2 (G), R6.1, R7.1
unnamed: Q5.2 (G), R16.1, SW3.1
unnamed: Q6.1 (D12_1), Q6.8 (D12_2)
unnamed: R1.1, U1.5 (D+)
unnamed: R2.2, U1.4 (D-)
unnamed: R3.1, U1.43 (PE2/~HWB)
unnamed: R5.2, U1.25 (PD0)
unnamed: R6.2, U1.26 (PD1)
unnamed: R15.1, SW2.1
RESET: J1.6, R4.2, SW1.2, U1.20 (~RESET)
ROW0: D90.1 (K), D96.1 (K), D99.1 (K), D104.1 (K), D110.1 (K), D115.1 (K), D120.1 (K), D125.1 (K), D131.1 (K), D136.1 (K), D141.1 (K), D147.1 (K), D153.1 (K), D159.1 (K), D165.1 (K), D169.1 (K), U1.41 (PC6)
ROW1: D91.1 (K), D97.1 (K), D100.1 (K), D105.1 (K), D111.1 (K), D116.1 (K), D121.1 (K), D126.1 (K), D132.1 (K), D137.1 (K), D142.1 (K), D148.1 (K), D154.1 (K), D160.1 (K), D170.1 (K), U1.42 (PC7)
ROW2: D92.1 (K), D101.1 (K), D106.1 (K), D112.1 (K), D117.1 (K), D122.1 (K), D127.1 (K), D133.1 (K), D138.1 (K), D143.1 (K), D149.1 (K), D155.1 (K), D161.1 (K), D166.1 (K), D171.1 (K), U1.54 (PF7)
ROW3: D93.1 (K), D102.1 (K), D107.1 (K), D113.1 (K), D118.1 (K), D123.1 (K), D128.1 (K), D134.1 (K), D139.1 (K), D144.1 (K), D150.1 (K), D156.1 (K), D162.1 (K), D172.1 (K), U1.51 (PA0)
ROW4: D94.1 (K), D108.1 (K), D114.1 (K), D119.1 (K), D124.1 (K), D129.1 (K), D135.1 (K), D140.1 (K), D145.1 (K), D151.1 (K), D157.1 (K), D163.1 (K), D167.1 (K), D173.1 (K), U1.50 (PA1)
ROW5: D95.1 (K), D98.1 (K), D103.1 (K), D109.1 (K), D130.1 (K), D146.1 (K), D152.1 (K), D158.1 (K), D164.1 (K), D168.1 (K), D174.1 (K), U1.49 (PA2)
RST_5V: J2.3, U1.14 (PB4)
SCLK_5V: J1.4, J2.8, U1.11 (PB1)
SS_5V: J2.5, R9.1, U1.10 (PB0)
VBUS_SENSE: C8.1, F1.1, J3.A4 (VBUS), J3.A9 (VBUS), J3.B4 (VBUS), J3.B9 (VBUS), Q3.2 (S), Q4.1 (G), R5.1, R14.2

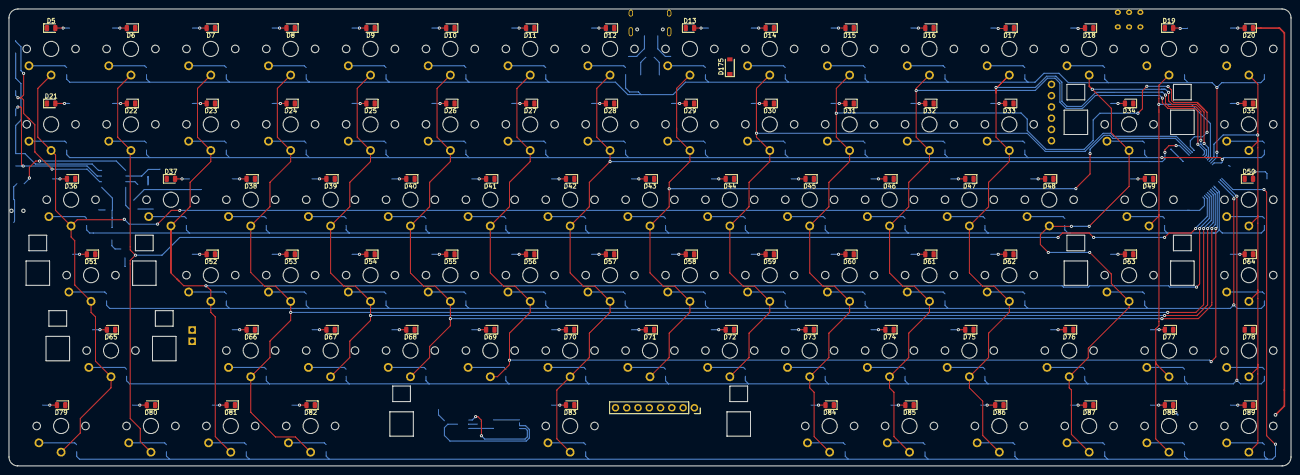
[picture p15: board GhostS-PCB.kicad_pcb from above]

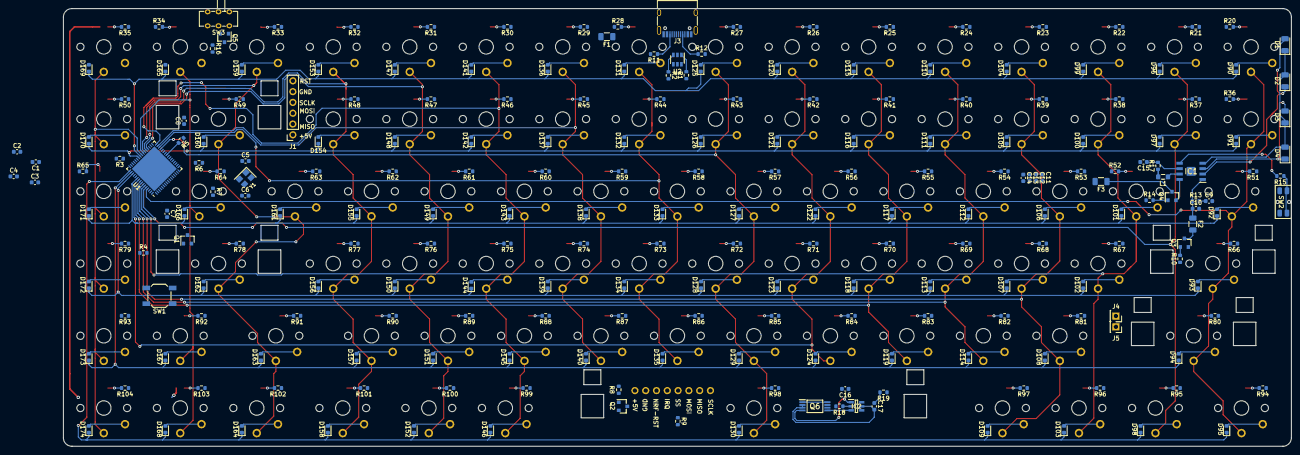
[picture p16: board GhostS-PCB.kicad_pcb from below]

Board: 2 copper layers, 289.0 x 103.0 mm, 404 parts (232 on the bottom side), 240 nets.

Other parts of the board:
D175: D_Schottky; D_SOD-123

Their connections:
+5V: D175.1; also elsewhere on the board

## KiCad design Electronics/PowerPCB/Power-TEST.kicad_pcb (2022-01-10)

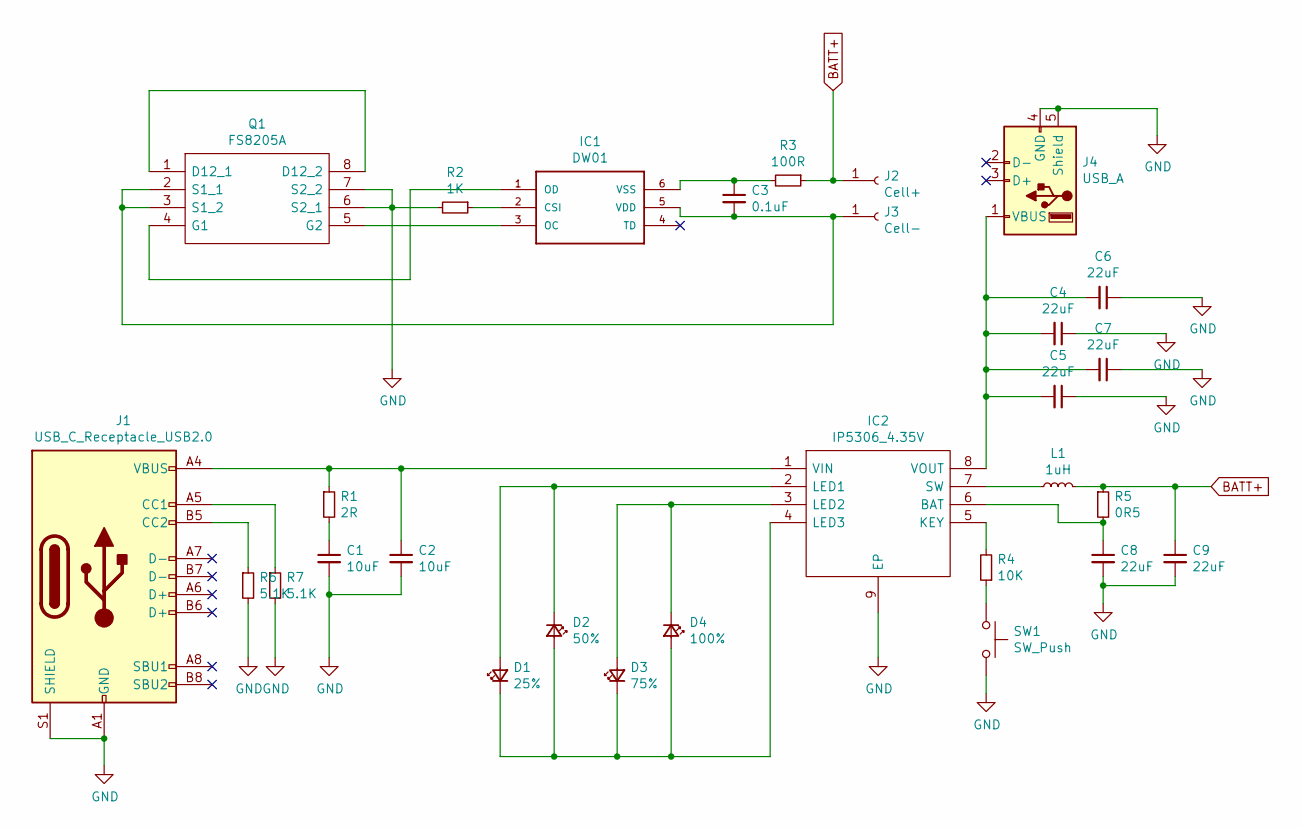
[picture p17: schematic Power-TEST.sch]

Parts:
C1, C2: 10uF; C_0805_2012Metric_Pad1.18x1.45mm_HandSolder
C3: 0.1uF; C_0603_1608Metric_Pad1.08x0.95mm_HandSolder
C4, C5, C6, C7, C8, C9: 22uF; C_0805_2012Metric_Pad1.18x1.45mm_HandSolder
D1: 25%; LED_0805_2012Metric_Pad1.15x1.40mm_HandSolder; LCSC C2290
D2: 50%; LED_0805_2012Metric_Pad1.15x1.40mm_HandSolder; LCSC C2290
D3: 75%; LED_0805_2012Metric_Pad1.15x1.40mm_HandSolder; LCSC C2290
D4: 100%; LED_0805_2012Metric_Pad1.15x1.40mm_HandSolder; LCSC C2290
IC1: DW01; LCSC C14213
IC2: IP5306_4.35V; IP5306; LCSC C384572
J1: USB_C_Receptacle_USB2.0; USB_C_Receptacle_HRO_TYPE-C-31-M-12; LCSC C136423
J2: Cell+; PinSocket_1x01_P2.54mm_Vertical
J3: Cell-; PinSocket_1x01_P2.54mm_Vertical
J4: USB_A; USB_A_Stewart_SS-52100-001_Horizontal; LCSC C2346
L1: 1uH; L_0805_2012Metric_Pad1.05x1.20mm_HandSolder
Q1: FS8205A; LCSC C16052
R1: 2R; R_0805_2012Metric_Pad1.20x1.40mm_HandSolder
R2: 1K; R_0805_2012Metric_Pad1.20x1.40mm_HandSolder
R3: 100R; R_0805_2012Metric_Pad1.20x1.40mm_HandSolder
R4: 10K; R_0805_2012Metric_Pad1.20x1.40mm_HandSolder
R5: 0R5; R_0805_2012Metric_Pad1.20x1.40mm_HandSolder
R6, R7: 5.1K; R_0805_2012Metric_Pad1.20x1.40mm_HandSolder
SW1: SW_Push; SW_PUSH_6mm_H4.3mm

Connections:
BATT+: C9.1, J2.1, L1.2, R3.1, R5.1
GND: C1.2, C2.2, C4.1, C5.1, C6.1, C7.1, C8.2, C9.2, IC2.9 (EP), J1.A1 (GND), J1.A12 (GND), J1.B1 (GND), J1.B12 (GND), J1.S1 (SHIELD), J4.4 (GND), J4.5 (Shield), Q1.6 (S2_1), Q1.7 (S2_2), R2.2, R6.2, R7.2, SW1.2
unnamed: C1.1, R1.2
unnamed: C2.1, IC2.1 (VIN), J1.A4 (VBUS), J1.A9 (VBUS), J1.B4 (VBUS), J1.B9 (VBUS), R1.1
unnamed: C3.1, IC1.6 (VSS), R3.2
unnamed: C3.2, IC1.5 (VDD), J3.1, Q1.2 (S1_1), Q1.3 (S1_2)
unnamed: C4.2, C5.2, C6.2, C7.2, IC2.8 (VOUT), J4.1 (VBUS)
unnamed: C8.1, IC2.6 (BAT), R5.2
unnamed: D1.1 (K), D2.2 (A), D3.1 (K), D4.2 (A), IC2.4 (LED3)
unnamed: D1.2 (A), D2.1 (K), IC2.2 (LED1)
unnamed: D3.2 (A), D4.1 (K), IC2.3 (LED2)
unnamed: IC1.1 (OD), Q1.4 (G1)
unnamed: IC1.2 (CSI), R2.1
unnamed: IC1.3 (OC), Q1.5 (G2)
unnamed: IC2.5 (KEY), R4.2
unnamed: IC2.7 (SW), L1.1
unnamed: J1.A5 (CC1), R7.1
unnamed: J1.B5 (CC2), R6.1
unnamed: Q1.1 (D12_1), Q1.8 (D12_2)
unnamed: R4.1, SW1.1

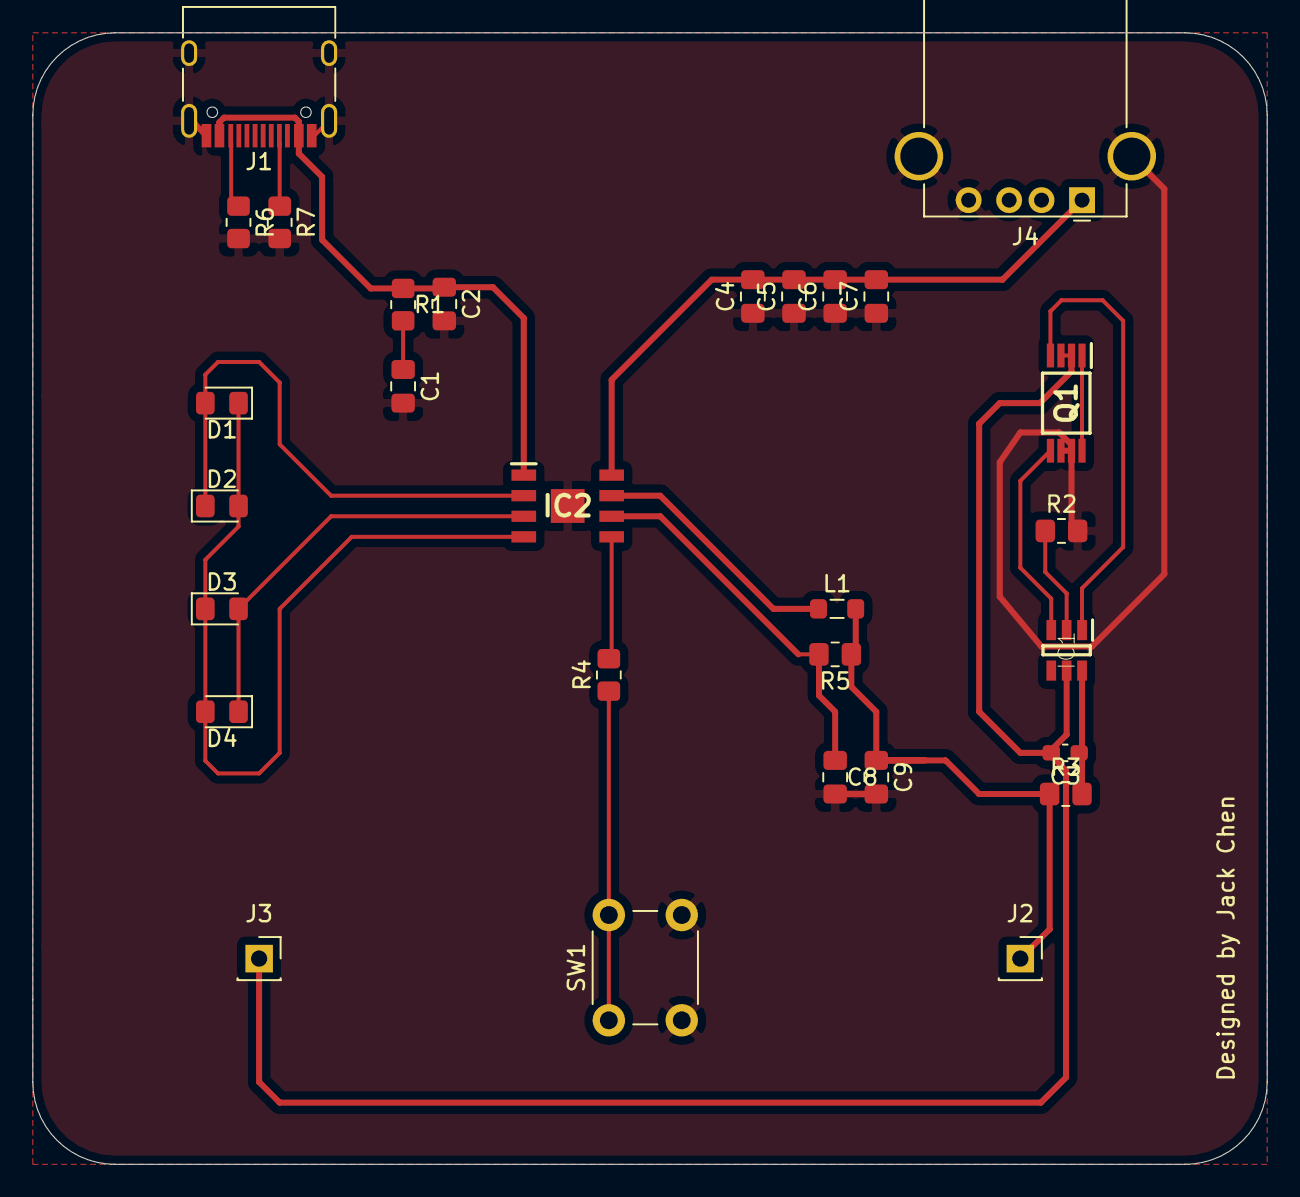
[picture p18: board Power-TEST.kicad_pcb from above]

Board: 2 copper layers, 76.2 x 69.8 mm, 29 parts (0 on the bottom side), 20 nets.
